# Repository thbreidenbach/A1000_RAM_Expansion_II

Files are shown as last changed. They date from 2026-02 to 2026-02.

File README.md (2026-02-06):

# A1000_RAM_Expansion_II
Modern Amiga 1000 Front Ram Expansion

This project is an effort to offer a modern appraoch to the Amiga 1000 front Ram Expansion.

The included PCB is untested as of now and will probably eithor not work or be subject to change after initial testing.
Thanks to Joachim Firnhaber for his help and good words (there's a lot of... potential), I would probably not have published the files without his okay.

I suggest Users wait until propper testing was done, before ordering boards.

Logic holds current **untested** code. Just like the PCB Design this is currently no more than a starting point or boilerplate. If you're adventurous and it works, leave me a message!!

**Back**



**Front**



The Board has Testpoints for RAM Glue-Logic so hopefully issues can be sorted out fast.
HTML BOM is included and should help sourcing parts. RAM should probably go with CY62128ELL Which is available in TSOP-32 Footprint at Reichelt at an extremely low price point. All Parts excluding the 60-Pin Connector are probably less than 20,-- EUR.

See License before ordering or going forward with this Design.

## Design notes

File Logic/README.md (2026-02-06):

# A1000 Front-RAM 256 KiB (ChipRAM) Expansion – XC9572XL + 2x 128Kx8 SRAM

This folder contains a complete *starting point* HDL + constraints + command-line build scripts
for an Amiga 1000 front expansion memory board.

## What this implements

- Replaces the classic “A1050 style” 256 KiB ChipRAM board (8x 64K×4 DRAM) with:
  - 2× 128K×8 async SRAM (e.g. CY7C109)
  - 1× XC9572XL CPLD as glue logic for multiplexed DRA[7:0], /RAS, /CASx, /RRW

## Electrical rationale

- XC9572XL I/O are **5 V tolerant inputs**, outputs are **3.3 V** (TTL-high compatible for 5 V SRAM with TTL inputs).
- CY7C109/CY62128ELL is a **5 V** SRAM with TTL-compatible inputs (4.5–5.5 V supply), so **no level shifting** is required for SRAM if you power it at 5 V.

## Connections overview (logic)

### From A1000 front connector to CPLD inputs
- DRA0..7  -> `dra[0..7]`
- /RAS     -> `ras_n`
- /RRW     -> `rrw_n`
- /CASL0,/CASU0,/CASL1,/CASU1 -> `casl0_n`, `casu0_n`, `casl1_n`, `casu1_n`

### From CPLD outputs to SRAMs
Common to both SRAMs:
- `sram_a[16:0]` -> A0..A16
- `ce2`          -> CE2 (active high)
- `oe_n`         -> /OE
- `we_n`         -> /WE

Low-byte SRAM:
- `ce1_l_n`      -> CE1 (active low)

High-byte SRAM:
- `ce1_u_n`      -> CE1 (active low)

### SRAM data bus
- Low-byte SRAM DQ0..7  -> Amiga D0..D7
- High-byte SRAM DQ0..7 -> Amiga D8..D15

## Files
- `a1000_frontram.v`   : Verilog top module
- `a1000_frontram.ucf` : Example pin constraints (adjust to your PCB!)
- `a1000_frontram.prj` : XST project file
- `a1000_frontram.xst` : XST run script
- `build.sh`           : Linux/macOS bash build (ISE tools in PATH)
- `build_windows.cmd`  : Windows build
- `pins.pcf`           : Informational pin map (ISE uses UCF)

## Build (command line)
- Linux/macOS:
  - `chmod +x build.sh`
  - `./build.sh`
- Windows:
  - ensure ISE bin is in PATH
  - `build_windows.cmd`

Outputs:
- `a1000_frontram.jed` : JEDEC programming file
- `a1000_frontram.svf` : SVF JTAG file

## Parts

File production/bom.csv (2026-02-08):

Designator | Footprint | Quantity | Value | LCSC Part #
C1 | 1206 | 1 | 22uF
C10, C3 | 0805 | 2 | 10uF
C11, C12, C2, C5, C6, C8, C9 | 0805 | 7 | 100nF
C4 | 0805 | 1 | C_Small
J1 | Connector_horizontal_amiga1.04_GREEN | 1 | Front_Connector
J2 | IDC-Header_2x05_P2.54mm_Vertical | 1 | Conn_02x05_Odd_Even
MINIUSB1 | USB_Mini-B_Wuerth_65100516121_Horizontal | 1 | USB_Mini-B_Wuerth
R17, R18, R19 | 0603 | 3 | 10k
RN1, RN2, RN3, RN4 | R_Array_Convex_4x0603 | 4 | 33r
SRAM_1, SRAM_2 | TSOP-I-32_18.4x8mm_P0.5mm | 2 | CY7C109D
U1 | TQFP-64_10x10mm_P0.5mm | 1 | XC9572XL-xxVQx64
U2 | SOT-223-3_TabPin2 | 1 | LD1117S33TR_SOT223

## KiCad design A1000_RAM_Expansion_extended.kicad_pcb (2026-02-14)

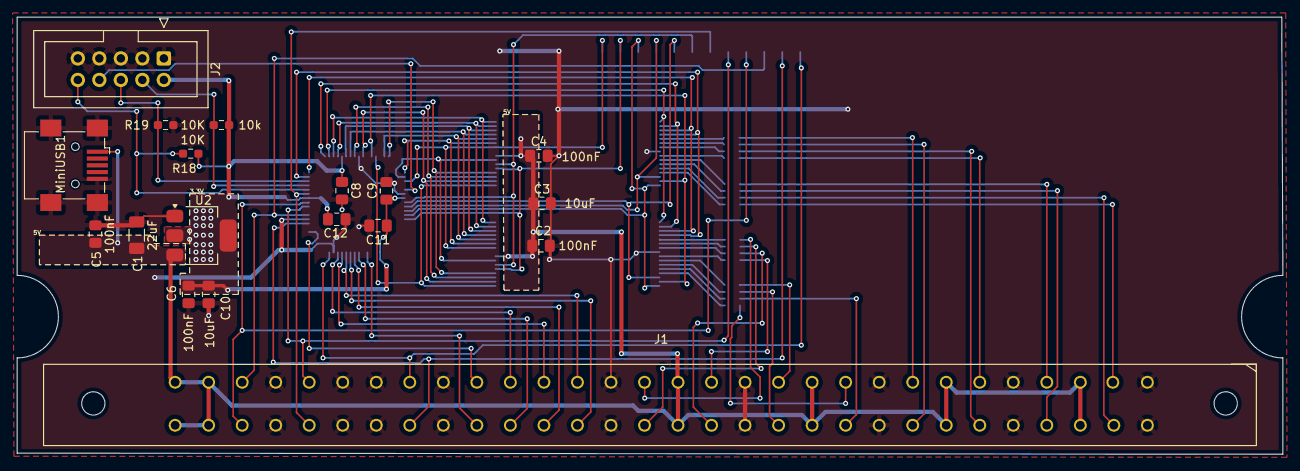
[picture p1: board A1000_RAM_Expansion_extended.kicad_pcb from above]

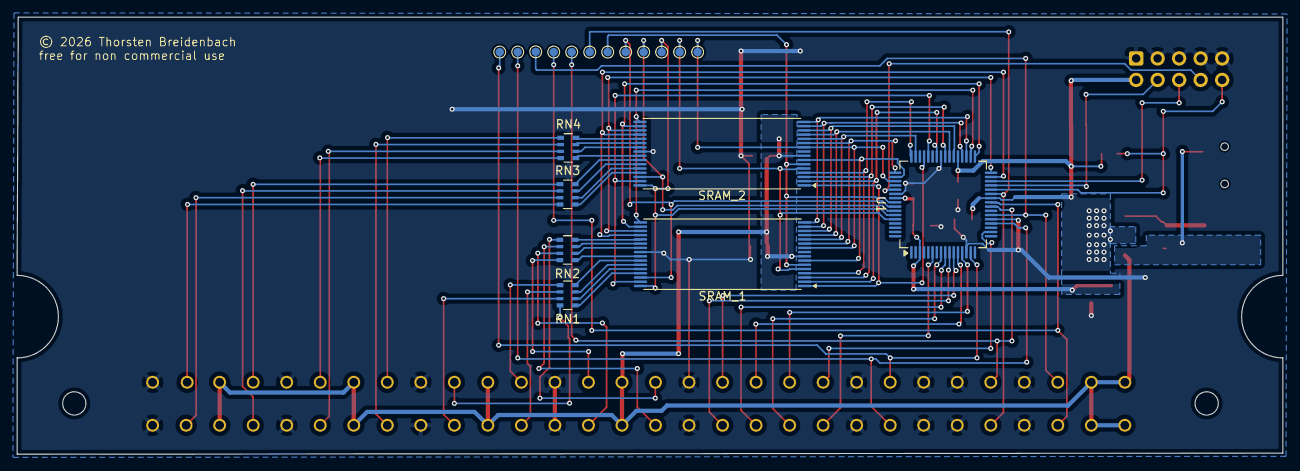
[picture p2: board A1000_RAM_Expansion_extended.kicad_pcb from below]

Board: 2 copper layers, 149.5 x 51.6 mm, 37 parts (19 on the bottom side), 75 nets.

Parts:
/casu_0, /casu_1: TestPoint_Pad_D1.0mm
/ce1_u: TestPoint_Pad_D1.0mm
/oe: TestPoint_Pad_D1.0mm
/ras: TestPoint_Pad_D1.0mm
/rrw: TestPoint_Pad_D1.0mm
/we: TestPoint_Pad_D1.0mm
C1: 22uF; C_1206_3216Metric_Pad1.33x1.80mm_HandSolder
C2, C5, C6, C8, C9, C11, C12: 100nF; C_0805_2012Metric_Pad1.18x1.45mm_HandSolder
C3, C10: 10uF; C_0805_2012Metric_Pad1.18x1.45mm_HandSolder
C4: C_Small; C_0805_2012Metric_Pad1.18x1.45mm_HandSolder
J1: Front_Connector; Connector_horizontal_amiga1.04_GREEN
J2: Conn_02x05_Odd_Even; IDC-Header_2x05_P2.54mm_Vertical
MiniUSB1: USB_Mini-B_Wuerth; USB_Mini-B_Wuerth_65100516121_Horizontal
R17: 10k; R_0603_1608Metric_Pad0.98x0.95mm_HandSolder
R18, R19: 10K; R_0603_1608Metric_Pad0.98x0.95mm_HandSolder
RN1, RN2, RN3, RN4: 33r; R_Array_Convex_4x0603
SRAM_1, SRAM_2: CY7C109D; TSOP-I-32_18.4x8mm_P0.5mm
U1: XC9572XL-xxVQx64; TQFP-64_10x10mm_P0.5mm
U2: LD1117S33TR_SOT223; SOT-223-3_TabPin2
casl0, casl1: TestPoint_Pad_D1.0mm
ce1_l, ce2: TestPoint_Pad_D1.0mm
sram_A16: TestPoint_Pad_D1.0mm

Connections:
+3.3V: C6.1, C8.1, C9.1, C10.1, C11.1, C12.1, J2.2, R17.2, R18.2, U1.3 (VCCINT), U1.26 (VCCIO), U1.37 (VCCINT), U1.55 (VCCIO), U2.2 (VO)
+5V: C1.1, C2.1, C3.1, C4.1, C5.1, J1.3, J1.7, J1.11, J1.15, J1.29, J1.30, J1.C (Pin_33), J1.H (Pin_37), J1.HH (Pin_59), J1.JJ (Pin_60), J1.M (Pin_41), J1.S (Pin_45), MiniUSB1.1 (VBUS), SRAM_1.8 (VCC), SRAM_2.8 (VCC), U2.3 (VI)
D0: J1.16, RN2.5 (R4.2)
D1: J1.T (Pin_46), RN2.6 (R3.2)
D2: J1.R (Pin_44), RN2.7 (R2.2)
D3: J1.14, RN2.8 (R1.2)
D4: J1.12, RN1.5 (R4.2)
D5: J1.N (Pin_42), RN1.6 (R3.2)
D6: J1.L (Pin_40), RN1.7 (R2.2)
D7: J1.10, RN1.8 (R1.2)
D8: J1.8, RN4.1 (R1.1)
D9: J1.J (Pin_38), RN4.2 (R2.1)
D10: J1.F (Pin_36), RN4.3 (R3.1)
D11: J1.6, RN4.4 (R4.1)
D12: J1.4, RN3.1 (R1.1)
D13: J1.D (Pin_34), RN3.2 (R2.1)
D14: J1.B (Pin_32), RN3.3 (R3.1)
D15: J1.2, RN3.4 (R4.1)
DRA0: J1.Y (Pin_51), U1.6 (I/O)
DRA1: J1.X (Pin_50), U1.8 (I/O)
DRA2: J1.W (Pin_49), U1.9 (I/O)
DRA3: J1.V (Pin_48), U1.10 (I/O)
DRA4: J1.18, U1.11 (I/O)
DRA5: J1.19, U1.12 (I/O)
DRA6: J1.20, U1.13 (I/O)
DRA7: J1.21, U1.18 (I/O)
GND: C1.2, C2.2, C3.2, C4.2, C5.2, C6.2, C8.2, C9.2, C10.2, C11.2, C12.2, J1.1, J1.5, J1.9, J1.13, J1.17, J1.22, J1.24, J1.25, J1.27, J1.A (Pin_31), J1.BB (Pin_54), J1.CC (Pin_55), J1.E (Pin_35), J1.EE, J1.K (Pin_39), J1.P (Pin_43), J1.U (Pin_47), J1.Z (Pin_52), J2.1, J2.3, J2.5, J2.7, J2.9, MiniUSB1.5 (GND), MiniUSB1.6 (Shield), R19.2, SRAM_1.24 (GND), SRAM_2.24 (GND), U1.14 (GND), U1.21 (GND), U1.41 (GND), U1.54 (GND), U2.1 (GND)
unnamed: RN1.1 (R1.1), SRAM_1.29 (I/O7)
unnamed: RN1.2 (R2.1), SRAM_1.28 (I/O6)
unnamed: RN1.3 (R3.1), SRAM_1.27 (I/O5)
unnamed: RN1.4 (R4.1), SRAM_1.26 (I/O4)
unnamed: RN2.1 (R1.1), SRAM_1.25 (I/O3)
unnamed: RN2.2 (R2.1), SRAM_1.23 (I/O2)
unnamed: RN2.3 (R3.1), SRAM_1.22 (I/O1)
unnamed: RN2.4 (R4.1), SRAM_1.21 (I/O0)
unnamed: RN3.8 (R1.2), SRAM_2.26 (I/O4)
unnamed: RN3.7 (R2.2), SRAM_2.27 (I/O5)
unnamed: RN3.6 (R3.2), SRAM_2.28 (I/O6)
unnamed: RN3.5 (R4.2), SRAM_2.29 (I/O7)
unnamed: RN4.8 (R1.2), SRAM_2.21 (I/O0)
unnamed: RN4.7 (R2.2), SRAM_2.22 (I/O1)
unnamed: RN4.6 (R3.2), SRAM_2.23 (I/O2)
unnamed: RN4.5 (R4.2), SRAM_2.25 (I/O3)
TCK: J2.6, R19.1, U1.30 (TCK)
TDI: J2.10, R18.1, U1.28 (TDI)
TDO: J2.8, U1.53 (TDO)
TMS: J2.4, R17.1, U1.29 (TMS)
ce2: SRAM_1.6 (CE2), SRAM_2.6 (CE2), U1.56 (I/O), ce2.7
sram_a0: SRAM_1.20 (A0), SRAM_2.20 (A0), U1.31 (I/O)
sram_a1: SRAM_1.19 (A1), SRAM_2.19 (A1), U1.32 (I/O)
sram_a2: SRAM_1.18 (A2), SRAM_2.18 (A2), U1.33 (I/O)
sram_a3: SRAM_1.17 (A3), SRAM_2.17 (A3), U1.34 (I/O)
sram_a4: SRAM_1.16 (A4), SRAM_2.16 (A4), U1.35 (I/O)
sram_a5: SRAM_1.15 (A5), SRAM_2.15 (A5), U1.36 (I/O)
sram_a6: SRAM_1.14 (A6), SRAM_2.14 (A6), U1.38 (I/O)
sram_a7: SRAM_1.13 (A7), SRAM_2.13 (A7), U1.39 (I/O)
sram_a8: SRAM_1.3 (A8), SRAM_2.3 (A8), U1.40 (I/O)
sram_a9: SRAM_1.2 (A9), SRAM_2.2 (A9), U1.42 (I/O)
sram_a10: SRAM_1.31 (A10), SRAM_2.31 (A10), U1.44 (I/O)
sram_a11: SRAM_1.1 (A11), SRAM_2.1 (A11), U1.45 (I/O)
sram_a12: SRAM_1.12 (A12), SRAM_2.12 (A12), U1.47 (I/O)
sram_a13: SRAM_1.4 (A13), SRAM_2.4 (A13), U1.48 (I/O)
sram_a14: SRAM_1.11 (A14), SRAM_2.11 (A14), U1.49 (I/O)
sram_a15: SRAM_1.7 (A15), SRAM_2.7 (A15), U1.50 (I/O)
sram_a16: SRAM_1.10 (A16), SRAM_2.10 (A16), U1.51 (I/O), sram_A16.12
/CASL0: J1.28, U1.22 (I/O), casl0.3
/CASL1: J1.FF (Pin_58), U1.25 (I/O), casl1.4
/CASU0: /casu_0.5, J1.26, U1.24 (I/O)
/CASU1: /casu_1.6, J1.DD (Pin_56), U1.27 (I/O)
/RAS: /ras.1, J1.23, U1.15 (I/O/GCK1)
/RRW: /rrw.2, J1.AA (Pin_53), U1.20 (I/O)
/ce1_l: SRAM_1.30 (_CE), U1.57 (I/O), ce1_l.8
/ce_1_u: /ce1_u.9, SRAM_2.30 (_CE), U1.58 (I/O)
/oe: /oe.10, SRAM_1.32 (_OE), SRAM_2.32 (_OE), U1.59 (I/O)
/we: /we.11, SRAM_1.5 (_WE), SRAM_2.5 (_WE), U1.60 (I/O)

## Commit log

2026-02-06 PCB Cleanup
    [A1000_RAM_Expansion_extended.kicad_pcb]
2026-02-06 BOM and Production files refresh
2026-02-08 Planes revised, gitignore
    [A1000_RAM_Expansion_extended.kicad_pcb]
2026-02-08 Production FIles & BOM
    [bom.csv, designators.csv, positions.csv]
2026-02-09 In da Zone..
    [A1000_RAM_Expansion_extended.kicad_pcb]
2026-02-14 wrong Pin Association.. Bummer
2026-02-14 bad tmd switch in build

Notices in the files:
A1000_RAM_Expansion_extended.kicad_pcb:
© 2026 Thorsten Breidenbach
